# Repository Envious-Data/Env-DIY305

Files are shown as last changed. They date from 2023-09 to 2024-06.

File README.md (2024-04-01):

# Env-DIY305
 A custom PCB implementation of the LTP305 as they are now discontinued.

## Info
the LTP305 is discontinued and I saw a project on hackaday where someone made their own LTP305 using 0201 LEDs on a DIP14 sized PCB so I thought since their pcb files were never released we can re-do it but open source it.

we've made our own but a couple of variations, hand soldering 0201 is hard and using PCBA is expensive for 0201 so there is a 0402 version, its not quite the same led position as the original displays but its functional and close enough as well as being decently cheap.

This is meant as a drop in replacement for the LTP305/TIL305 so we plan for it to work the same except without the diffuser cover and also with other colours.

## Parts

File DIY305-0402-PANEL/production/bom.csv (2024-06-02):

Designator | Footprint | Quantity | Value | LCSC Part #
D1_8, D1_7, D1_6, D1_5, D1_4, D1_3, D1_2, D1, D10_8, D10_7, D10_6, D10_5, D10_4, D10_3, D10_2, D10, D11_8, D11_7, D11_6, D11_5, D11_4, D11_3, D11_2, D11, D12_8, D12_7, D12_6, D12_5, D12_4, D12_3, D12_2, D12, D13_8, D13_7, D13_6, D13_5, D13_4, D13_3, D13_2, D13, D14_8, D14_7, D14_6, D14_5, D14_4, D14_3, D14_2, D14, D15_8, D15_7, D15_6, D15_5, D15_4, D15_3, D15_2, D15, D16_8, D16_7, D16_6, D16_5, D16_4, D16_3, D16_2, D16, D17_8, D17_7, D17_6, D17_5, D17_4, D17_3, D17_2, D17, D18_8, D18_7, D18_6, D18_5, D18_4, D18_3, D18_2, D18, D19_8, D19_7, D19_6, D19_5, D19_4, D19_3, D19_2, D19, D2_8, D2_7, D2_6, D2_5, D2_4, D2_3, D2_2, D2, D20_8, D20_7, D20_6, D20_5, D20_4, D20_3, D20_2, D20, D21_8, D21_7, D21_6, D21_5, D21_4, D21_3, D21_2, D21, D22_8, D22_7, D22_6, D22_5, D22_4, D22_3, D22_2, D22, D23_8, D23_7, D23_6, D23_5, D23_4, D23_3, D23_2, D23, D24_8, D24_7, D24_6, D24_5, D24_4, D24_3, D24_2, D24, D25_8, D25_7, D25_6, D25_5, D25_4, D25_3, D25_2, D25, D26_8, D26_7, D26_6, D26_5, D26_4, D26_3, D26_2, D26, D27_8, D27_7, D27_6, D27_5, D27_4, D27_3, D27_2, D27, D28_8, D28_7, D28_6, D28_5, D28_4, D28_3, D28_2, D28, D29_8, D29_7, D29_6, D29_5, D29_4, D29_3, D29_2, D29, D3_8, D3_7, D3_6, D3_5, D3_4, D3_3, D3_2, D3, D30_8, D30_7, D30_6, D30_5, D30_4, D30_3, D30_2, D30, D31_8, D31_7, D31_6, D31_5, D31_4, D31_3, D31_2, D31 | 0402 | 200 | LED
D32_8, D32_7, D32_6, D32_5, D32_4, D32_3, D32_2, D32, D33_8, D33_7, D33_6, D33_5, D33_4, D33_3, D33_2, D33, D34_8, D34_7, D34_6, D34_5, D34_4, D34_3, D34_2, D34, D35_8, D35_7, D35_6, D35_5, D35_4, D35_3, D35_2, D35, D36_8, D36_7, D36_6, D36_5, D36_4, D36_3, D36_2, D36, D4_8, D4_7, D4_6, D4_5, D4_4, D4_3, D4_2, D4, D5_8, D5_7, D5_6, D5_5, D5_4, D5_3, D5_2, D5, D6_8, D6_7, D6_6, D6_5, D6_4, D6_3, D6_2, D6, D7_8, D7_7, D7_6, D7_5, D7_4, D7_3, D7_2, D7, D8_8, D8_7, D8_6, D8_5, D8_4, D8_3, D8_2, D8, D9_8, D9_7, D9_6, D9_5, D9_4, D9_3, D9_2, D9 | 0402 | 88 | LED
J3_8, J3_7, J3_6, J3_5, J3_4, J3_3, J3_2, J3 | PinHeader_1x14_P1.00mm_Vertical | 8 | Conn_01x14
KiKit_MB_10_1, KiKit_MB_10_2, KiKit_MB_10_3, KiKit_MB_10_4, KiKit_MB_10_5, KiKit_MB_10_6, KiKit_MB_10_7, KiKit_MB_11_1, KiKit_MB_11_2, KiKit_MB_11_3, KiKit_MB_11_4, KiKit_MB_11_5, KiKit_MB_11_6, KiKit_MB_11_7, KiKit_MB_12_1, KiKit_MB_12_2, KiKit_MB_12_3, KiKit_MB_12_4, KiKit_MB_12_5, KiKit_MB_12_6, KiKit_MB_12_7, KiKit_MB_13_1, KiKit_MB_13_2, KiKit_MB_13_3, KiKit_MB_13_4, KiKit_MB_13_5, KiKit_MB_13_6, KiKit_MB_13_7, KiKit_MB_14_1, KiKit_MB_14_2, KiKit_MB_14_3, KiKit_MB_14_4, KiKit_MB_14_5, KiKit_MB_14_6, KiKit_MB_14_7, KiKit_MB_15_1, KiKit_MB_15_2, KiKit_MB_15_3, KiKit_MB_15_4, KiKit_MB_15_5, KiKit_MB_15_6, KiKit_MB_15_7, KiKit_MB_16_1, KiKit_MB_16_2, KiKit_MB_16_3, KiKit_MB_16_4, KiKit_MB_16_5, KiKit_MB_16_6, KiKit_MB_16_7, KiKit_MB_17_1, KiKit_MB_17_2, KiKit_MB_17_3, KiKit_MB_17_4, KiKit_MB_18_1, KiKit_MB_18_2, KiKit_MB_18_3, KiKit_MB_18_4, KiKit_MB_19_1, KiKit_MB_19_2, KiKit_MB_19_3, KiKit_MB_19_4, KiKit_MB_1_1, KiKit_MB_1_2, KiKit_MB_1_3, KiKit_MB_1_4, KiKit_MB_1_5, KiKit_MB_1_6, KiKit_MB_1_7, KiKit_MB_20_1, KiKit_MB_20_2, KiKit_MB_20_3, KiKit_MB_20_4, KiKit_MB_21_1, KiKit_MB_21_2, KiKit_MB_21_3, KiKit_MB_21_4, KiKit_MB_22_1, KiKit_MB_22_2, KiKit_MB_22_3, KiKit_MB_22_4, KiKit_MB_23_1, KiKit_MB_23_2, KiKit_MB_23_3, KiKit_MB_23_4, KiKit_MB_24_1, KiKit_MB_24_2, KiKit_MB_24_3, KiKit_MB_24_4, KiKit_MB_2_1, KiKit_MB_2_2, KiKit_MB_2_3, KiKit_MB_2_4, KiKit_MB_2_5, KiKit_MB_2_6, KiKit_MB_2_7, KiKit_MB_3_1, KiKit_MB_3_2, KiKit_MB_3_3, KiKit_MB_3_4, KiKit_MB_3_5, KiKit_MB_3_6, KiK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 | NPTH | 144 | NPTH

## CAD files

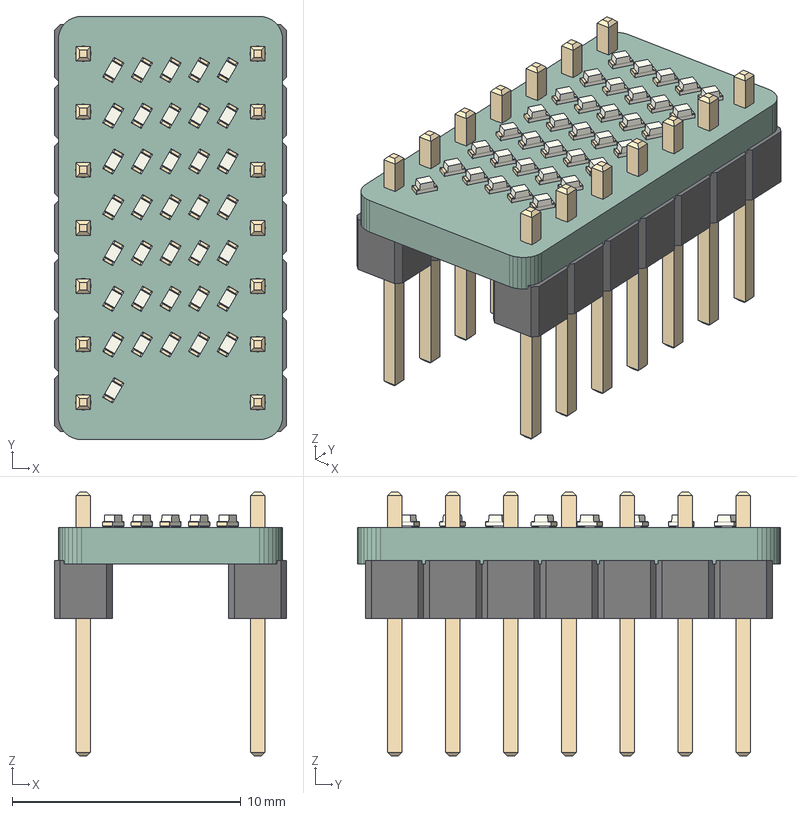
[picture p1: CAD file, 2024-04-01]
DIY305-0402/DIY305.step
10.2 x 18.5 x 11.5 mm
LED_0402_1005Metric x 36
PinHeader_1x07_P254mm_Vertical x 2
DIY305 PCB

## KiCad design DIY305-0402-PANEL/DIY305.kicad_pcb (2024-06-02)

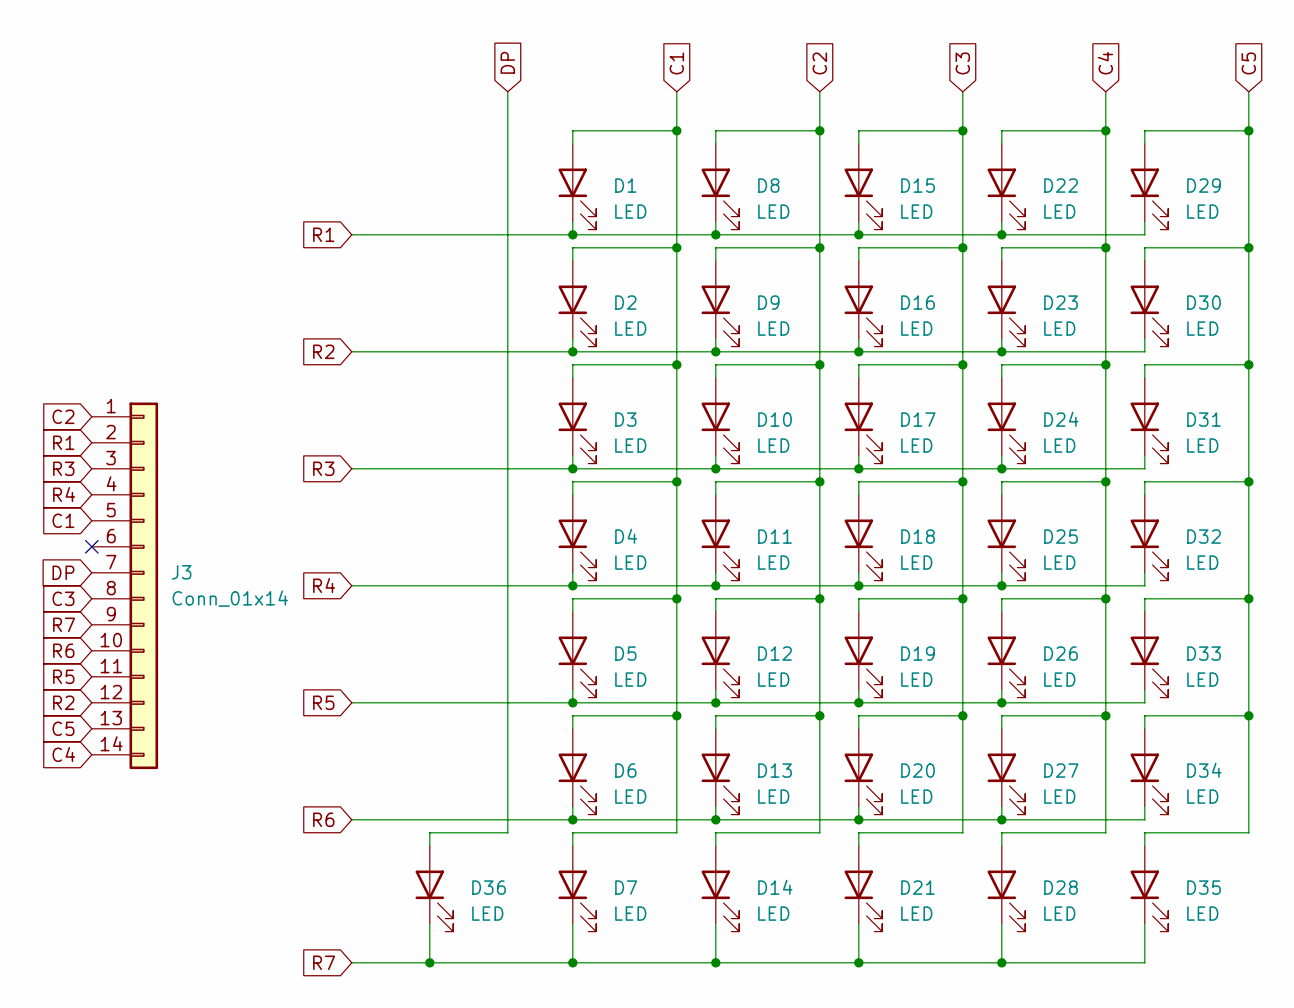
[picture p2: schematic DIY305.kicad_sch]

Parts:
D1, D2, D3, D4, D5, D6, D7, D8, D9, D10, D11, D12, D13, D14, D15, D16, D17, D18, D19, D20, D21, D22, D23, D24, D25, D26, D27, D28, D29, D30, D31, D32, D33, D34, D35, D36: LED; LED_0402_1005Metric
J3: Conn_01x14; PinHeader_1x14_P1.00mm_Vertical

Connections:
C1: D1.2 (A), D2.2 (A), D3.2 (A), D4.2 (A), D5.2 (A), D6.2 (A), D7.2 (A), J3.5
C2: D8.2 (A), D9.2 (A), D10.2 (A), D11.2 (A), D12.2 (A), D13.2 (A), D14.2 (A), J3.1
C3: D15.2 (A), D16.2 (A), D17.2 (A), D18.2 (A), D19.2 (A), D20.2 (A), D21.2 (A), J3.8
C4: D22.2 (A), D23.2 (A), D24.2 (A), D25.2 (A), D26.2 (A), D27.2 (A), D28.2 (A), J3.14
C5: D29.2 (A), D30.2 (A), D31.2 (A), D32.2 (A), D33.2 (A), D34.2 (A), D35.2 (A), J3.13
DP: D36.2 (A), J3.7
R1: D1.1 (K), D8.1 (K), D15.1 (K), D22.1 (K), D29.1 (K), J3.2
R2: D2.1 (K), D9.1 (K), D16.1 (K), D23.1 (K), D30.1 (K), J3.12
R3: D3.1 (K), D10.1 (K), D17.1 (K), D24.1 (K), D31.1 (K), J3.3
R4: D4.1 (K), D11.1 (K), D18.1 (K), D25.1 (K), D32.1 (K), J3.4
R5: D5.1 (K), D12.1 (K), D19.1 (K), D26.1 (K), D33.1 (K), J3.11
R6: D6.1 (K), D13.1 (K), D20.1 (K), D27.1 (K), D34.1 (K), J3.10
R7: D7.1 (K), D14.1 (K), D21.1 (K), D28.1 (K), D35.1 (K), D36.1 (K), J3.9

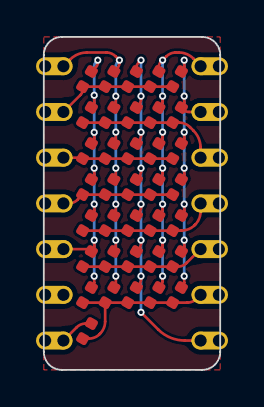
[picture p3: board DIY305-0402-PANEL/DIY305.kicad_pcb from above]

Board: 2 copper layers, 9.8 x 18.5 mm, 37 parts (0 on the bottom side), 13 nets.

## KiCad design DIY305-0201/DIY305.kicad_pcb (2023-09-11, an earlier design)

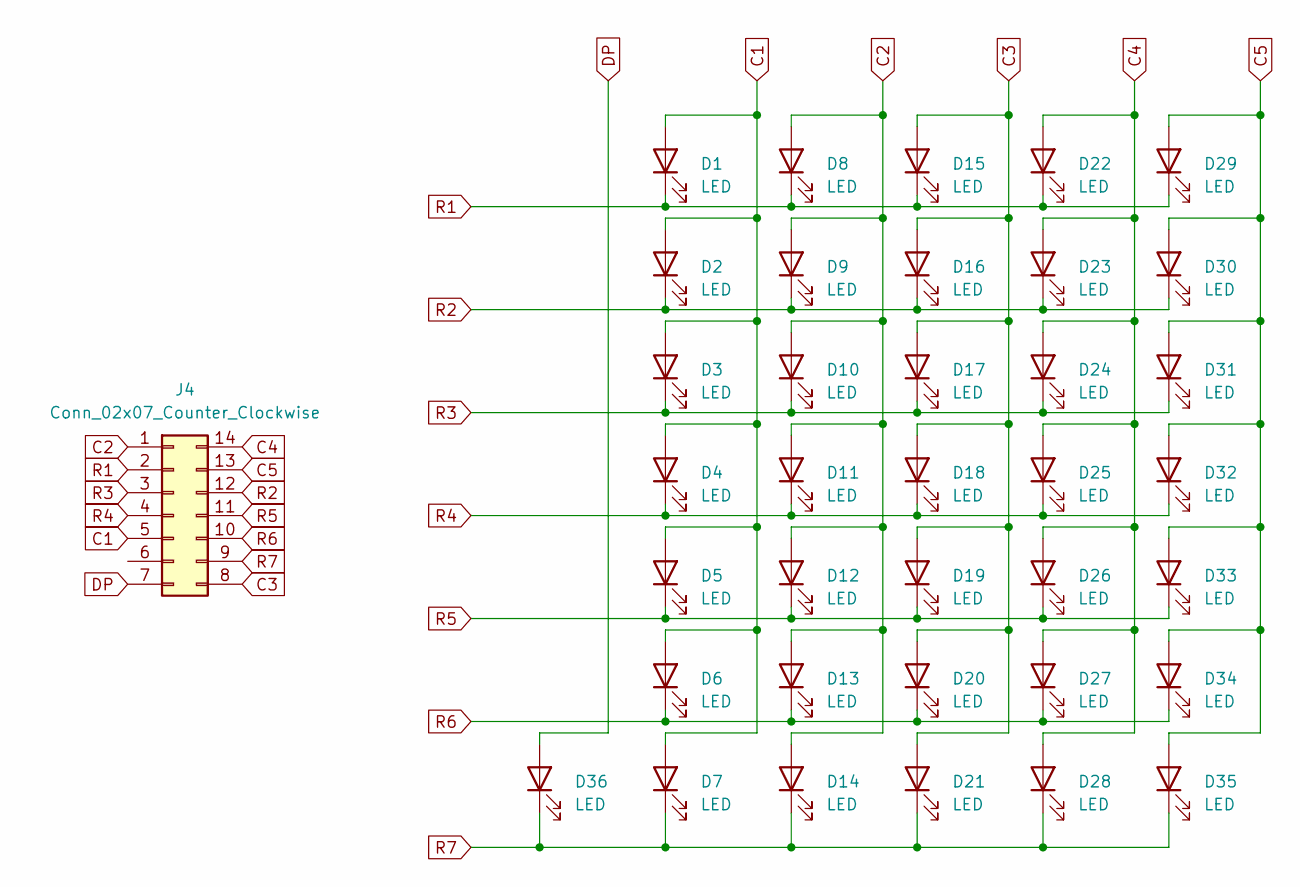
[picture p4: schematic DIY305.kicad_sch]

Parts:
D1, D2, D3, D4, D5, D6, D7, D8, D9, D10, D11, D12, D13, D14, D15, D16, D17, D18, D19, D20, D21, D22, D23, D24, D25, D26, D27, D28, D29, D30, D31, D32, D33, D34, D35, D36: LED; LED_0201_0603Metric
J4: Conn_02x07_Counter_Clockwise

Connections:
C1: D1.2 (A), D2.2 (A), D3.2 (A), D4.2 (A), D5.2 (A), D6.2 (A), D7.2 (A), J4.5
C2: D8.2 (A), D9.2 (A), D10.2 (A), D11.2 (A), D12.2 (A), D13.2 (A), D14.2 (A), J4.1
C3: D15.2 (A), D16.2 (A), D17.2 (A), D18.2 (A), D19.2 (A), D20.2 (A), D21.2 (A), J4.8
C4: D22.2 (A), D23.2 (A), D24.2 (A), D25.2 (A), D26.2 (A), D27.2 (A), D28.2 (A), J4.14
C5: D29.2 (A), D30.2 (A), D31.2 (A), D32.2 (A), D33.2 (A), D34.2 (A), D35.2 (A), J4.13
DP: D36.2 (A), J4.7
R1: D1.1 (K), D8.1 (K), D15.1 (K), D22.1 (K), D29.1 (K), J4.2
R2: D2.1 (K), D9.1 (K), D16.1 (K), D23.1 (K), D30.1 (K), J4.12
R3: D3.1 (K), D10.1 (K), D17.1 (K), D24.1 (K), D31.1 (K), J4.3
R4: D4.1 (K), D11.1 (K), D18.1 (K), D25.1 (K), D32.1 (K), J4.4
R5: D5.1 (K), D12.1 (K), D19.1 (K), D26.1 (K), D33.1 (K), J4.11
R6: D6.1 (K), D13.1 (K), D20.1 (K), D27.1 (K), D34.1 (K), J4.10
R7: D7.1 (K), D14.1 (K), D21.1 (K), D28.1 (K), D35.1 (K), D36.1 (K), J4.9

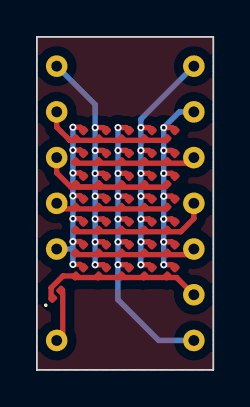
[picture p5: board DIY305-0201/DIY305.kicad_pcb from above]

Board: 2 copper layers, 9.8 x 18.5 mm, 37 parts (0 on the bottom side), 13 nets.

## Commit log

2023-09-10 Version 1.0
    [DIY305.kicad_pcb, DIY305.kicad_sch]
2023-09-10 Created panelised version
    [Panel-DIY305.kicad_sch]
2023-09-11 Version 2 with panelization and 0402 design
    [DIY305.kicad_pcb, DIY305.kicad_sch]
2023-09-11 Generated Panel
    [Panel-DIY305.kicad_pcb]
2023-09-12 created 305-0402 ALT and adjusted git ignore, might need another fix.
    [DIY305.kicad_pcb, DIY305.kicad_sch]
2023-09-12 finished up DIY-305-0402-ALT and fixed gitignore.
    [DIY305.kicad_pcb, bom.csv, designators.csv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]
2023-09-12 panelized the board and generated gerber, single bom and cpl only.
    [DIY305.kicad_pcb, DIY305.kicad_sch, bom.csv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]
2023-10-06 started work on manually paneling the pcb so I can get a more accurate price quote.
    [DIY305.kicad_pcb, DIY305.kicad_sch]
2024-01-15 Removal of old design
    [DIY305.kicad_pcb, DIY305.kicad_sch, Panel-DIY305.kicad_pcb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]
2024-01-15 Added largo panel
    [DIY305.kicad_pcb, DIY305.kicad_sch, bom.csv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]
2024-02-15 Fixed silly flip error
    [DIY305.kicad_pcb]
2024-02-15 Added iPirie's logo and corrected single trace to reduce possibility of mechanical damage to PCB
    [DIY305.kicad_pcb]
2024-02-15 Added pannel
    [DIY305.kicad_pcb, panel.kicad_pcb]
2024-03-01 Fixed spacing of pins and corrected orientation, made holes bigger and made tracks curvey with teardrops.
    [DIY305.kicad_pcb, DIY305.kicad_sch]
2024-04-01 generated step model for DIY305
    [DIY305.kicad_pcb, DIY305.step]
2024-05-31 added castellations to the DIY305
    [DIY305.kicad_pcb]
2024-06-02 generated panel and production files
    [DIY305.kicad_pcb, DIY305.kicad_sch, bom.csv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]
2024-06-02 made correct panel size
    [bom.csv, designators.csv, positions.csv]
